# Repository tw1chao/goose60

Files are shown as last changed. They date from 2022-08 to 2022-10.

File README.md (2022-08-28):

# goose60

goose60 是一個 60% 鍵盤 PCB 電路板專案。
設計目標是做出一把**無光害的熱插拔鍵盤**，MCU 採用 ARM Cortex-M3 的 STM32F103。所有按鍵位置皆支援軸體熱插拔，本系列含子專案皆為無光害版本，故電路上僅會有的 `caps lock` 指示燈。

goose60 支援標準60%布局，下面表格列出子專案及支援的布局。

| Sub-Project | Layout |
|---|---|
| JY60 | HHKB |
| Cattle60 | ISO |

未來視情況需要，再新增其他布局的子專案。

## 3D 預覽

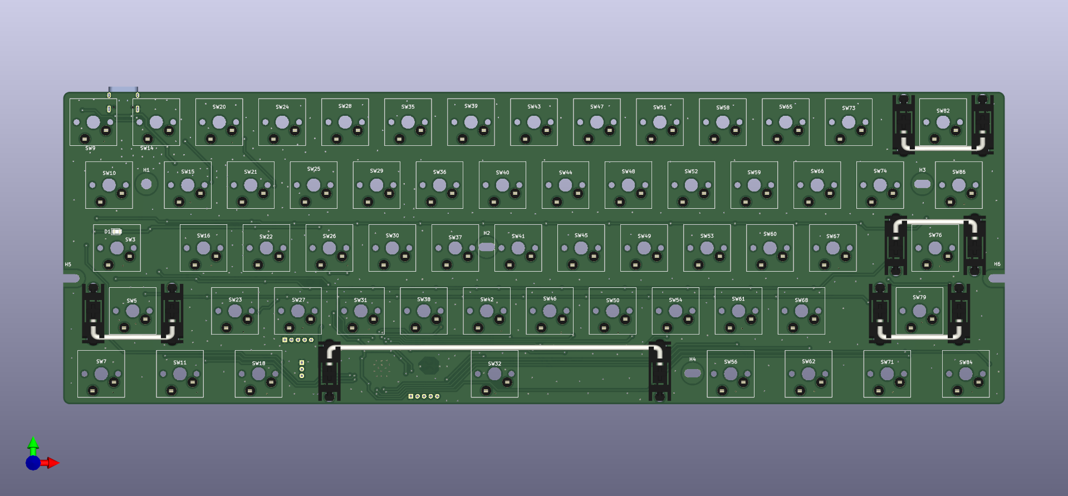
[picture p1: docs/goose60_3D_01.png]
goose60正面

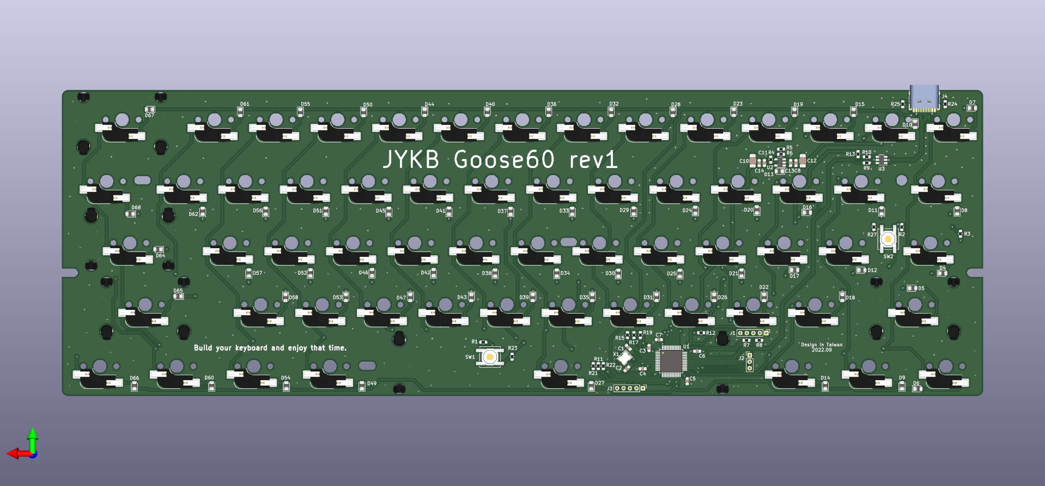
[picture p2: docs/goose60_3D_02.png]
goose60反面


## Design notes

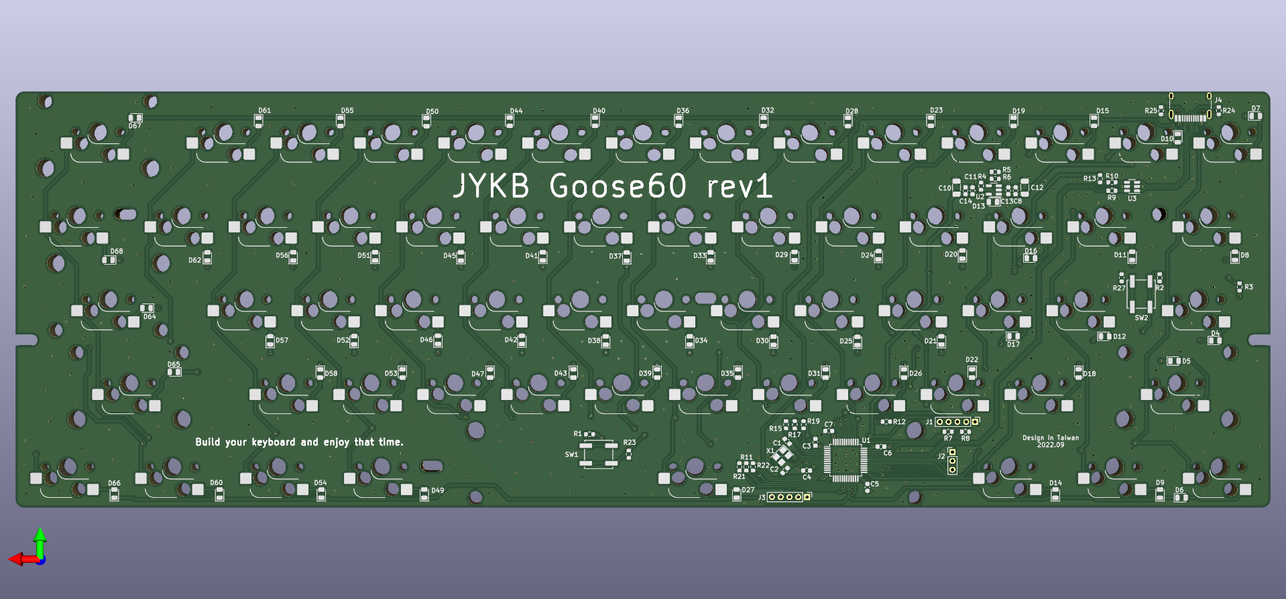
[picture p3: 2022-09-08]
docs/goose60_3D_02_nofp.png

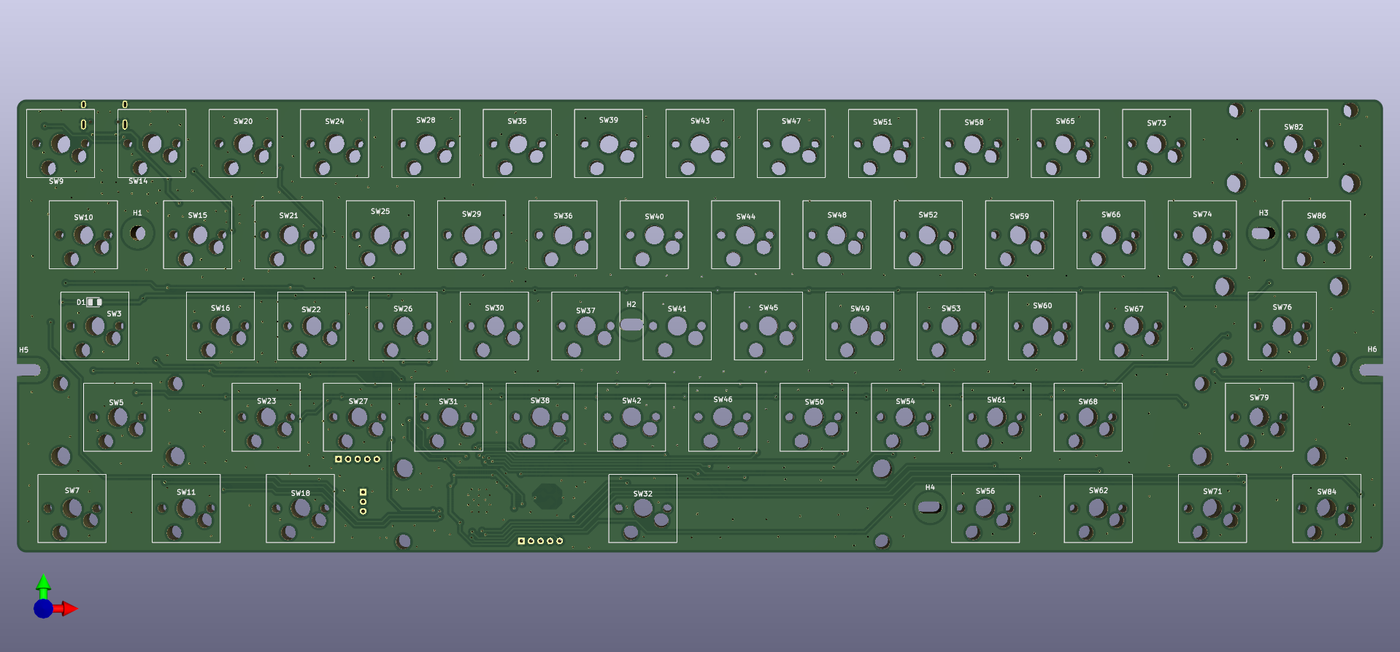
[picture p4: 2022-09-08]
docs/goose60_3D_01_nofp.png

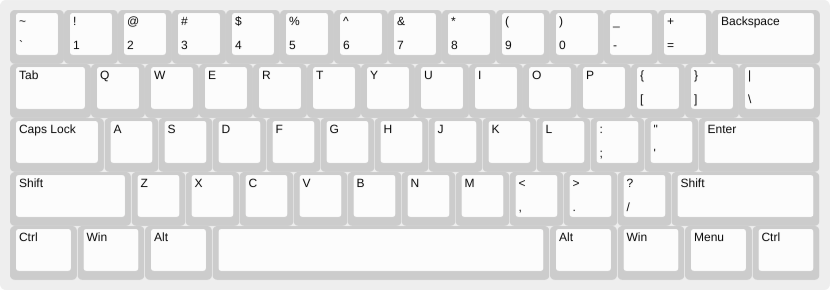
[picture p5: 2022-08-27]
docs/goose60_layout_default.png

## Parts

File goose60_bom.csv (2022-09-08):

ID | 指示符 | 軟體包 | 數量 | 名稱 | 供應商和參考
1 | SW53,SW5,SW71,SW22,SW3,SW10,SW11,SW52,SW20,SW61,SW27,SW35,SW76,SW9,SW65,SW29,SW37,SW41,SW23,SW21,SW82,SW79,SW58,SW67,SW25,SW18,SW59,SW46,SW28,SW43,SW16,SW15,SW7,SW31,SW39,SW73,SW54,SW60,SW32,SW44,SW30,SW47,SW84,SW38,SW45,SW74,SW86,SW40,SW66,SW24,SW50,SW62,SW42,SW48,SW56,SW51,SW49,SW26,SW14,SW36,SW68 | SW_Hotswap_Kailh_MX | 61 | SW_Push
2 | H6,H4,H2,H3,H5,H1 | MountingHole_3.2mm_M3_Pad_TopOnly | 6 | MountingHole
3 | D1 | LED_0805_2012Metric | 1 | LED
4 | C14,C13,C3 | C_0603_1608Metric | 3 | 1uF/16V
5 | D36,D8,D32,D61,D20,D42,D52,D12,D44,D37,D62,D10,D5,D60,D43,D65,D55,D9,D49,D39,D30,D54,D50,D7,D28,D67,D6,D41,D25,D21,D64,D58,D68,D35,D57,D26,D15,D16,D24,D47,D27,D51,D33,D40,D14,D13,D18,D46,D38,D17,D23,D19,D11,D22,D66,D29,D45,D53,D4,D34,D31,D56 | D_0805_2012Metric | 62 | 1N4148
6 | H8,H7 | NetTie-2_SMD_Pad0.5mm | 2 | MountingHole_Pad
7 | R27,R23 | R_0603_1608Metric | 2 | 100K/5%
8 | C7,C5,C6,C11,C8,C4 | C_0603_1608Metric | 6 | 100nF/16V
9 | SW1,SW2 | SW_Push_1P1T_NO_CK_KSC6xxJ | 2 | SW_Push
10 | R3 | R_0603_1608Metric | 1 | 330R/5%
11 | R24,R25 | R_0603_1608Metric | 2 | 5.1K/5%
12 | R10,R9 | R_0603_1608Metric | 2 | 22R/5%
13 | C1,C2 | C_0603_1608Metric | 2 | 22pF/50V
14 | R11,R8,R22,R17,R7,R5,R2,R15,R21,R19,R1 | R_0603_1608Metric | 11 | 10K/5%
15 | R12 | R_0603_1608Metric | 1 | 0R/5%
16 | R4 | R_0603_1608Metric | 1 | 39K/5%
17 | J1 | PinHeader_1x05_P2.00mm_Vertical | 1 | Debugger
18 | R13 | R_0603_1608Metric | 1 | 1.5K/5%
19 | R6 | R_0603_1608Metric | 1 | 100R/5%
20 | U1 | LQFP-48_7x7mm_P0.5mm | 1 | STM32F103CBTx
21 | J3 | PinHeader_1x05_P2.00mm_Vertical | 1 | SPI
22 | C12,C10 | C_1206_3216Metric | 2 | 100uF/16V
23 | J4 | USB_C_Receptacle_HRO_TYPE-C-31-M-12 | 1 | USB_C_Receptacle_USB2.0
24 | X1 | Crystal_SMD_TXC_7M-4Pin_3.2x2.5mm | 1 | Crystal_GND24
25 | U3 | SOT-23-6 | 1 | USBLC6-2SC6
26 | J2 | PinHeader_1x03_P2.00mm_Vertical | 1 | USART
27 | U2 | SOT-23-5 | 1 | TLV75533PDBV

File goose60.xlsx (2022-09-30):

Source: |  | goose60/goose60.kicad_sch
Date:
Tool: |  | Eeschema (6.0.4-0)
Component Count: |  |  | 177
ID | 指示符 | 軟體包 | 數量 | 名稱 | 供應商和參考 | Column1
1 | SW53,SW5,SW71,SW22,SW3,SW10,SW11,SW52,SW20,SW61,SW27,SW35,SW76,SW9,SW65,SW29,SW37,SW41,SW23,SW21,SW82,SW79,SW58,SW67,SW25,SW18,SW59,SW46,SW28,SW43,SW16,SW15,SW7,SW31,SW39,SW73,SW54,SW60,SW32,SW44,SW30,SW47,SW84,SW38,SW45,SW74,SW86,SW40,SW66,SW24,SW50,SW62,SW42,SW48,SW56,SW51,SW49,SW26,SW14,SW36,SW68 | SW_Hotswap_Kailh_MX | 61 | SW_Push
2 | H6,H4,H2,H3,H5,H1 | MountingHole_3.2mm_M3_Pad_TopOnly | 6 | MountingHole
3 | D1 | LED_0805_2012Metric | 1 | LED | https://www.mouser.tw/ProductDetail/Wurth-Elektronik/150080VS75000?qs=LlUlMxKIyB0tGHJmO6%252B0ug%3D%3D
4 | C14,C13,C3 | C_0603_1608Metric | 3 | 1uF/16V | https://www.mouser.tw/ProductDetail/Murata-Electronics/GRM188R61C105MA12D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
5 | D36,D8,D32,D61,D20,D42,D52,D12,D44,D37,D62,D10,D5,D60,D43,D65,D55,D9,D49,D39,D30,D54,D50,D7,D28,D67,D6,D41,D25,D21,D64,D58,D68,D35,D57,D26,D15,D16,D24,D47,D27,D51,D33,D40,D14,D13,D18,D46,D38,D17,D23,D19,D11,D22,D66,D29,D45,D53,D4,D34,D31,D56 | D_0805_2012Metric | 62 | 1N4148 | https://www.mouser.tw/ProductDetail/onsemi-Fairchild/1N4148WS?qs=2%2FYqgE%252BHg%252BKBrKZlAsMLhw%3D%3D
6 | H8,H7 | NetTie-2_SMD_Pad0.5mm | 2 | MountingHole_Pad
7 | R27,R23 | R_0603_1608Metric | 2 | 100K/5% | https://www.mouser.tw/ProductDetail/YAGEO/RC0603JR-07100KL?qs=2cAdsCoAWRG9Rhqklpdeqg%3D%3D
8 | C7,C5,C6,C11,C8,C4 | C_0603_1608Metric | 6 | 100nF/16V | https://www.mouser.tw/ProductDetail/Murata-Electronics/GCM188R71C104KA37J?qs=bGEzvQhTDnZD08oWyjLpYQ%3D%3D
9 | SW1,SW2 | SW_Push_1P1T_NO_CK_KSC6xxJ | 2 | SW_Push
10 | R3 | R_0603_1608Metric | 1 | 330R/5% | https://www.mouser.tw/ProductDetail/YAGEO/AF0603JR-07330RL?qs=tggtontpCXPNcXdAMAy2YQ%3D%3D
11 | R24,R25 | R_0603_1608Metric | 2 | 5.1K/5% | https://www.mouser.tw/ProductDetail/YAGEO/RC0603JR-075K1L?qs=%2F9ZTgpVJnN7YQQgCYZ3hbA%3D%3D
12 | R10,R9 | R_0603_1608Metric | 2 | 22R/5% | https://www.mouser.tw/ProductDetail/YAGEO/RC0603JR-0722RL?qs=%2F9ZTgpVJnN5zDbBVzV1%252B0w%3D%3D
13 | C1,C2 | C_0603_1608Metric | 2 | 22pF/50V | https://www.mouser.tw/ProductDetail/Murata-Electronics/GRM1885C1H220JA01D?qs=1a7qSHAimREG7dNFtPQaOQ%3D%3D
14 | R11,R8,R22,R17,R7,R5,R2,R15,R21,R19,R1 | R_0603_1608Metric | 11 | 10K/5% | https://www.mouser.tw/ProductDetail/YAGEO/RC0603JR-1010KL?qs=IuGqVx9wL0JvLpaswiKGwg%3D%3D
15 | R12 | R_0603_1608Metric | 1 | 0R/5% | https://www.mouser.tw/ProductDetail/YAGEO/RC0603JR-130RL?qs=C8jtsoXSqHT5F5yUCaWiAg%3D%3D
16 | R4 | R_0603_1608Metric | 1 | 39K/5% | https://www.mouser.tw/ProductDetail/YAGEO/RC0603JR-0739KL?qs=%2F9ZTgpVJnN6Z5Io8QsNeJw%3D%3D
17 | J1 | PinHeader_1x05_P2.00mm_Vertical | 1 | Debugger
18 | R13 | R_0603_1608Metric | 1 | 1.5K/5% | https://www.mouser.tw/ProductDetail/YAGEO/RC0603JR-071K5L?qs=%2F9ZTgpVJnN5lp5nC9oG1iw%3D%3D
19 | R6 | R_0603_1608Metric | 1 | 100R/5% | https://www.mouser.tw/ProductDetail/YAGEO/RC0603JR-13100RL?qs=fRxXYNj8ftFxOzR%252BbxPHAw%3D%3D
20 | U1 | LQFP-48_7x7mm_P0.5mm | 1 | STM32F103CBTx | https://www.mouser.tw/ProductDetail/STMicroelectronics/STM32F103CBT6?qs=WxFF5lh7QM3goh6GV5Ogig%3D%3D
21 | J3 | PinHeader_1x05_P2.00mm_Vertical | 1 | SPI
22 | C12,C10 | C_1206_3216Metric | 2 | 100uF/16V | https://www.mouser.tw/ProductDetail/Murata-Electronics/GRM31CR60G107MEA8L?qs=hd1VzrDQEGj2cLQFhjz5Pg%3D%3D
23 | J4 | USB_C_Receptacle_HRO_TYPE-C-31-M-12 | 1 | USB_C_Receptacle_USB2.0
24 | X1 | Crystal_SMD_TXC_7M-4Pin_3.2x2.5mm | 1 | Crystal_GND24 | https://www.mouser.tw/ProductDetail/Wurth-Elektronik/830108313809?qs=hd1VzrDQEGg8Y0DXLkvT4A%3D%3D
25 | U3 | SOT-23-6 | 1 | USBLC6-2SC6 | https://www.mouser.tw/ProductDetail/STMicroelectronics/USBLC6-2SC6?qs=po45yt2pPpu%2FhNIlwQdTlg%3D%3D
26 | J2 | PinHeader_1x03_P2.00mm_Vertical | 1 | USART
27 | U2 | SOT-23-5 | 1 | TLV75533PDBV | https://www.mouser.tw/ProductDetail/Texas-Instruments/TLV75533PDBVR?qs=55YtniHzbhAKEwqeO2xJXQ%3D%3D

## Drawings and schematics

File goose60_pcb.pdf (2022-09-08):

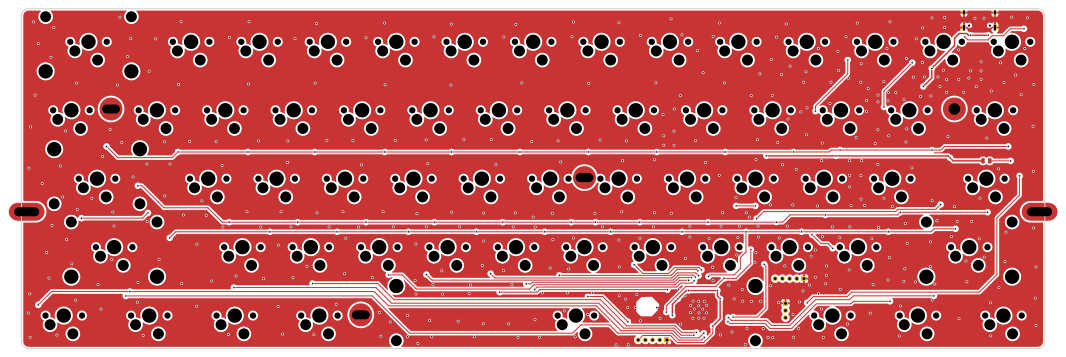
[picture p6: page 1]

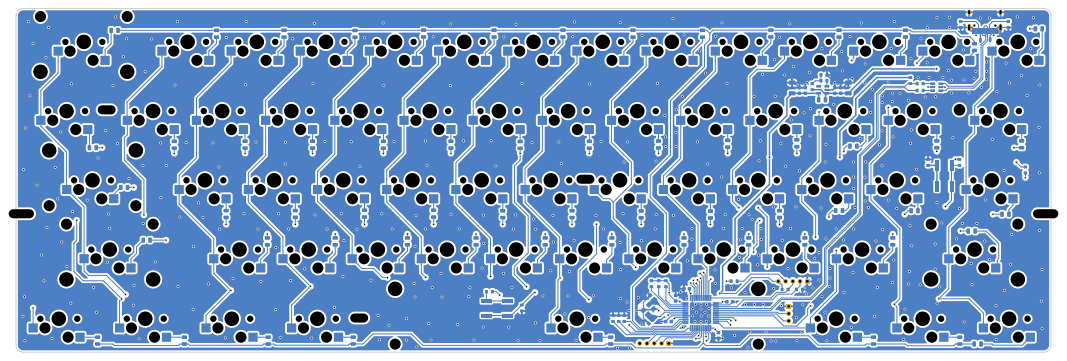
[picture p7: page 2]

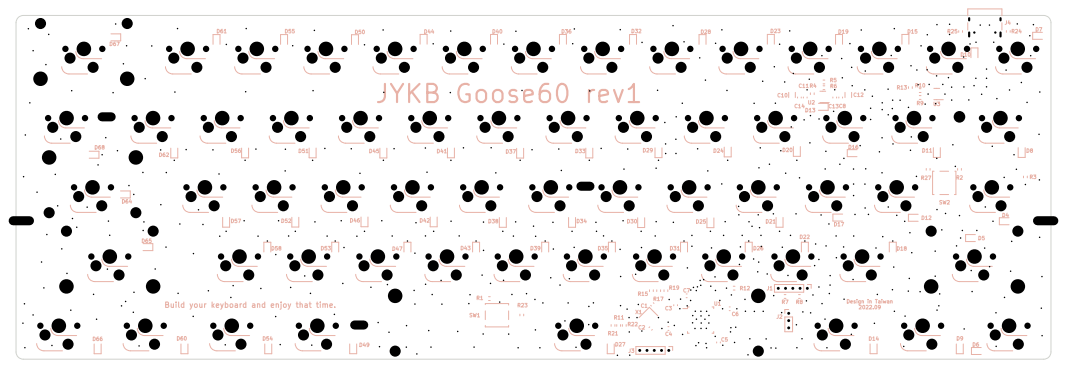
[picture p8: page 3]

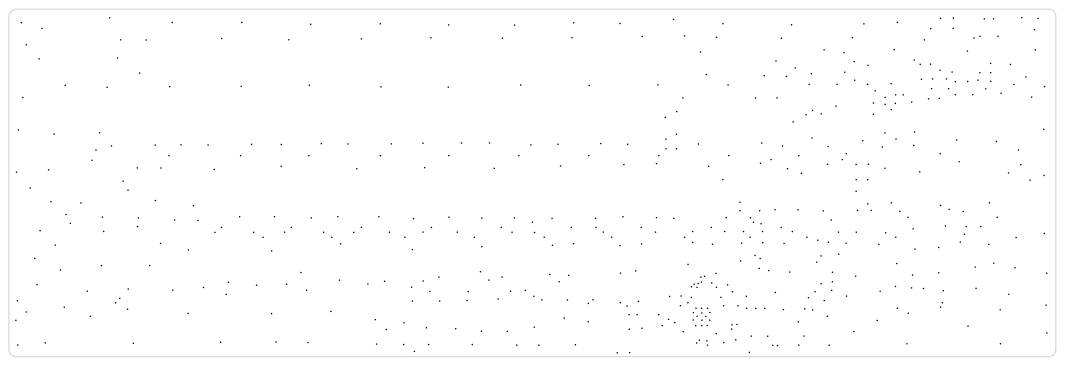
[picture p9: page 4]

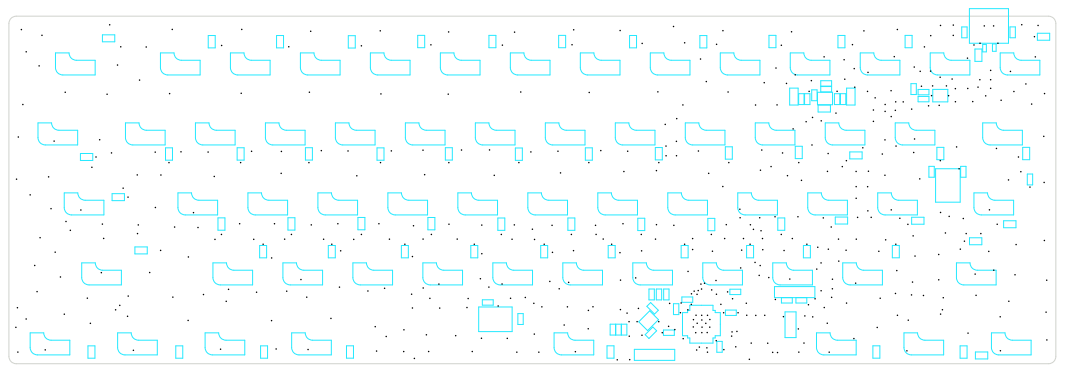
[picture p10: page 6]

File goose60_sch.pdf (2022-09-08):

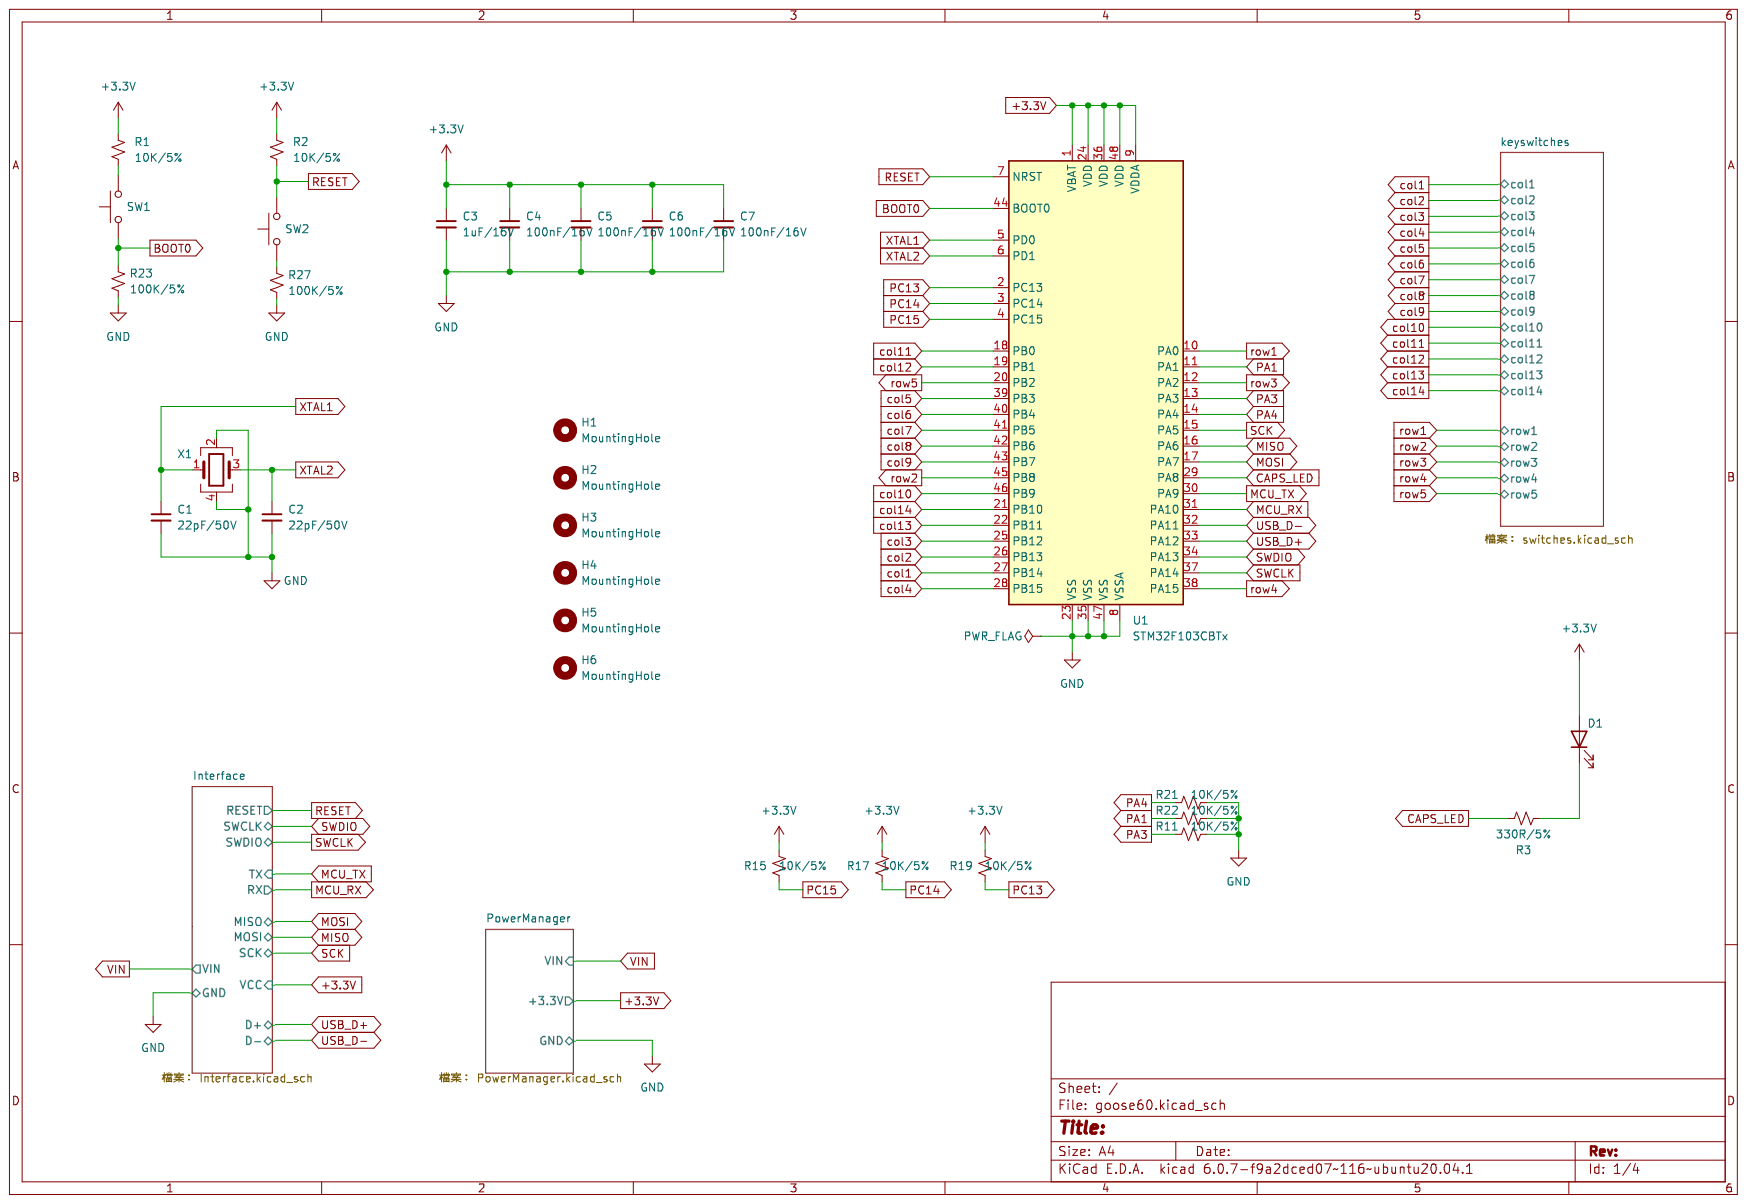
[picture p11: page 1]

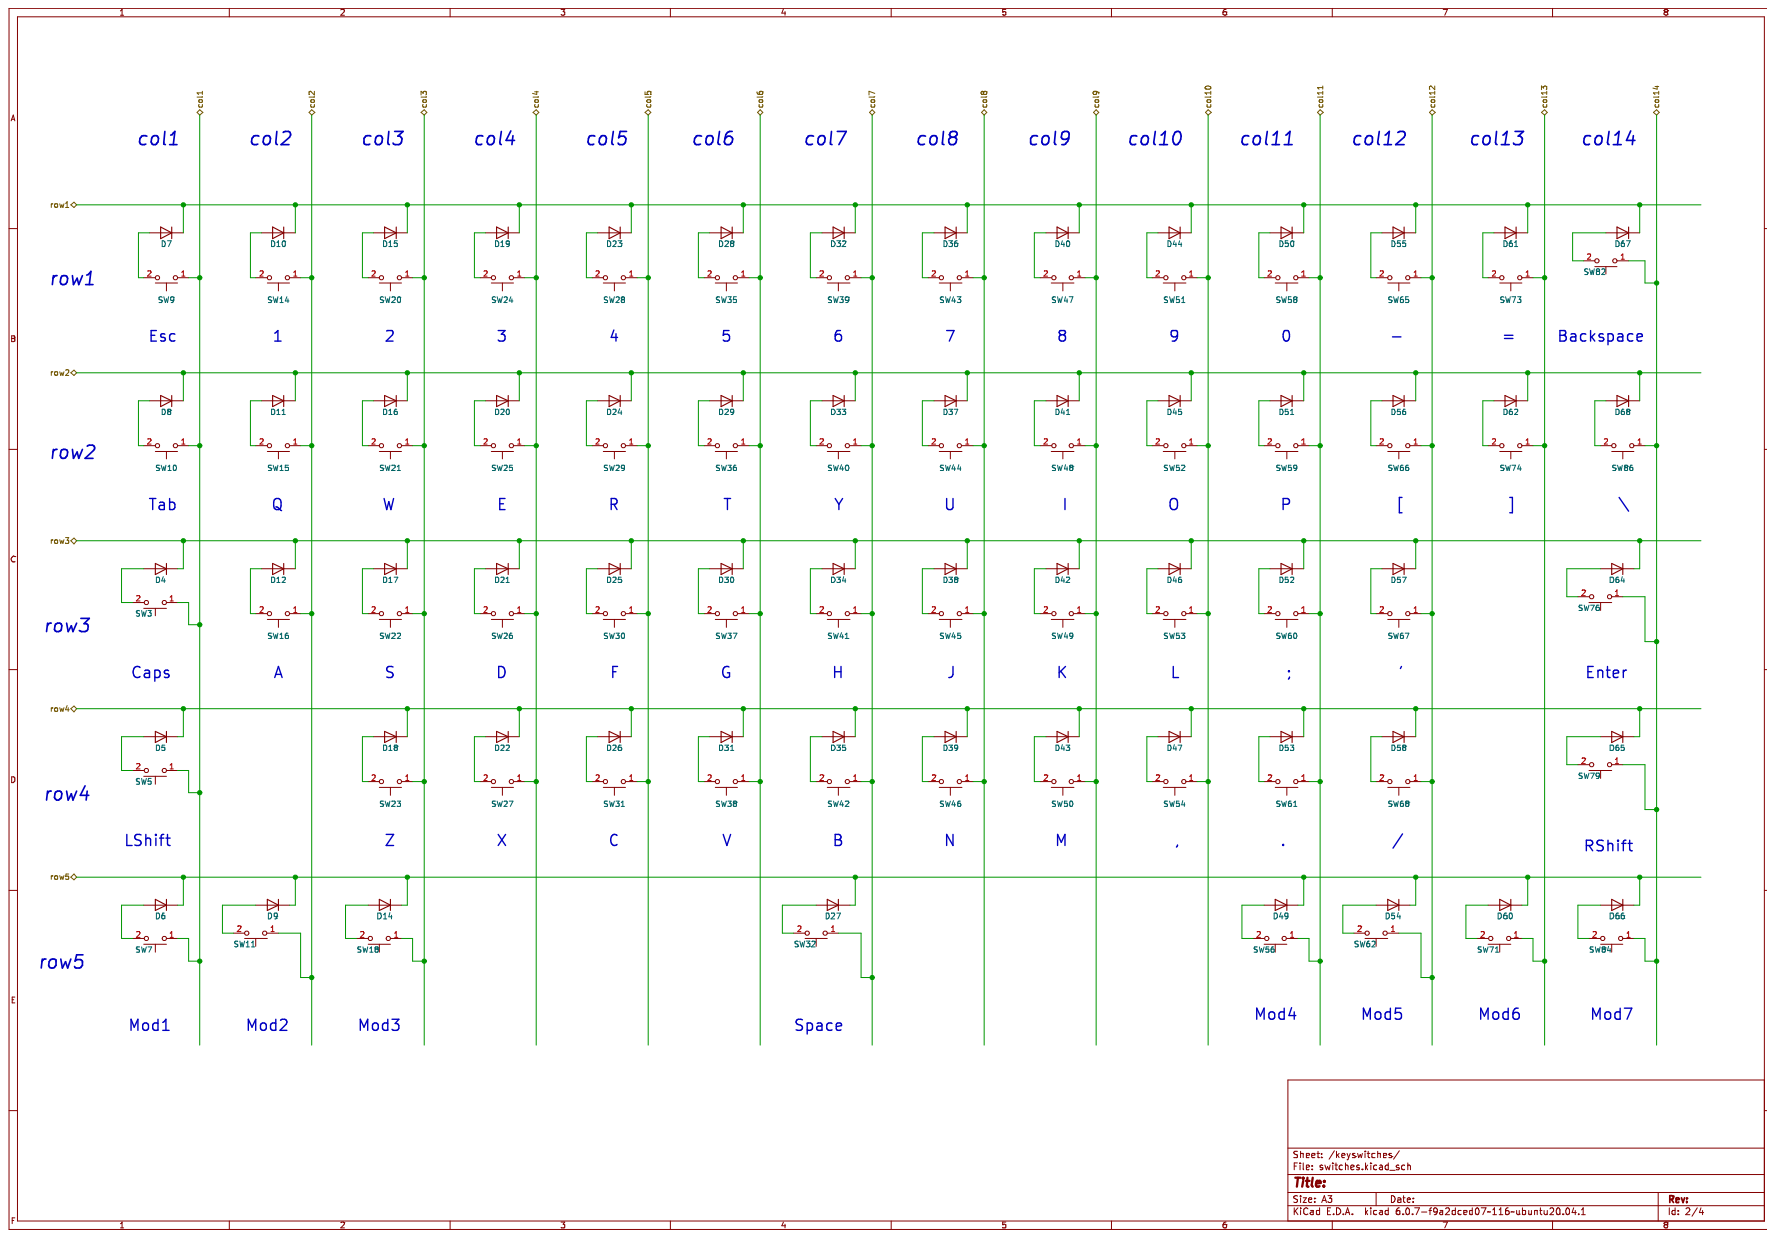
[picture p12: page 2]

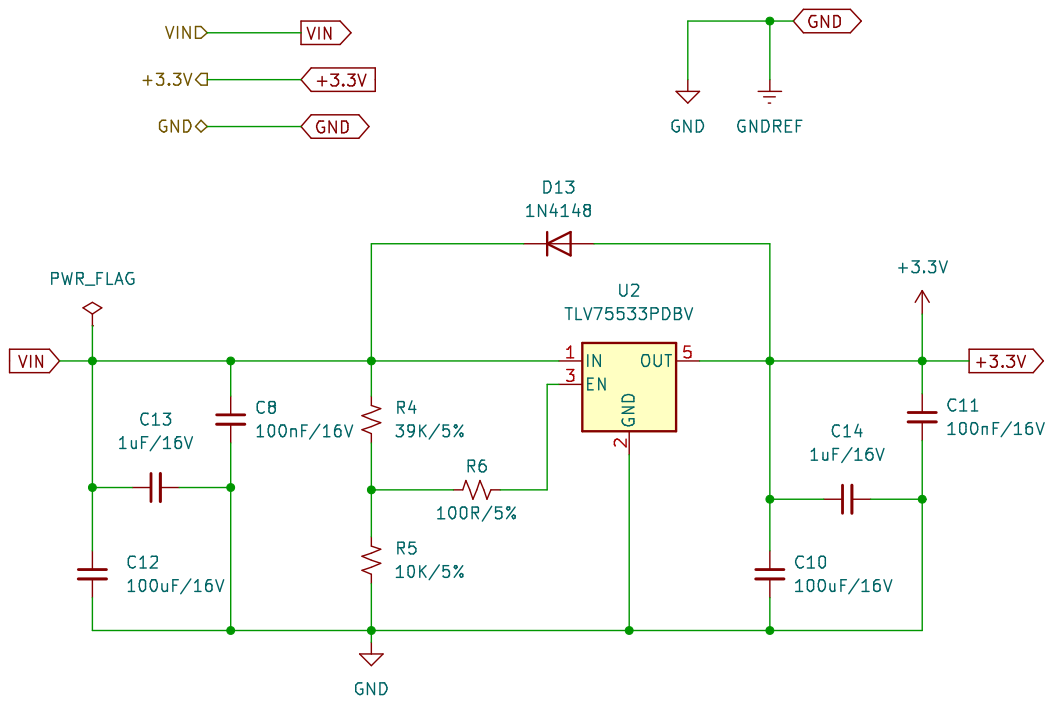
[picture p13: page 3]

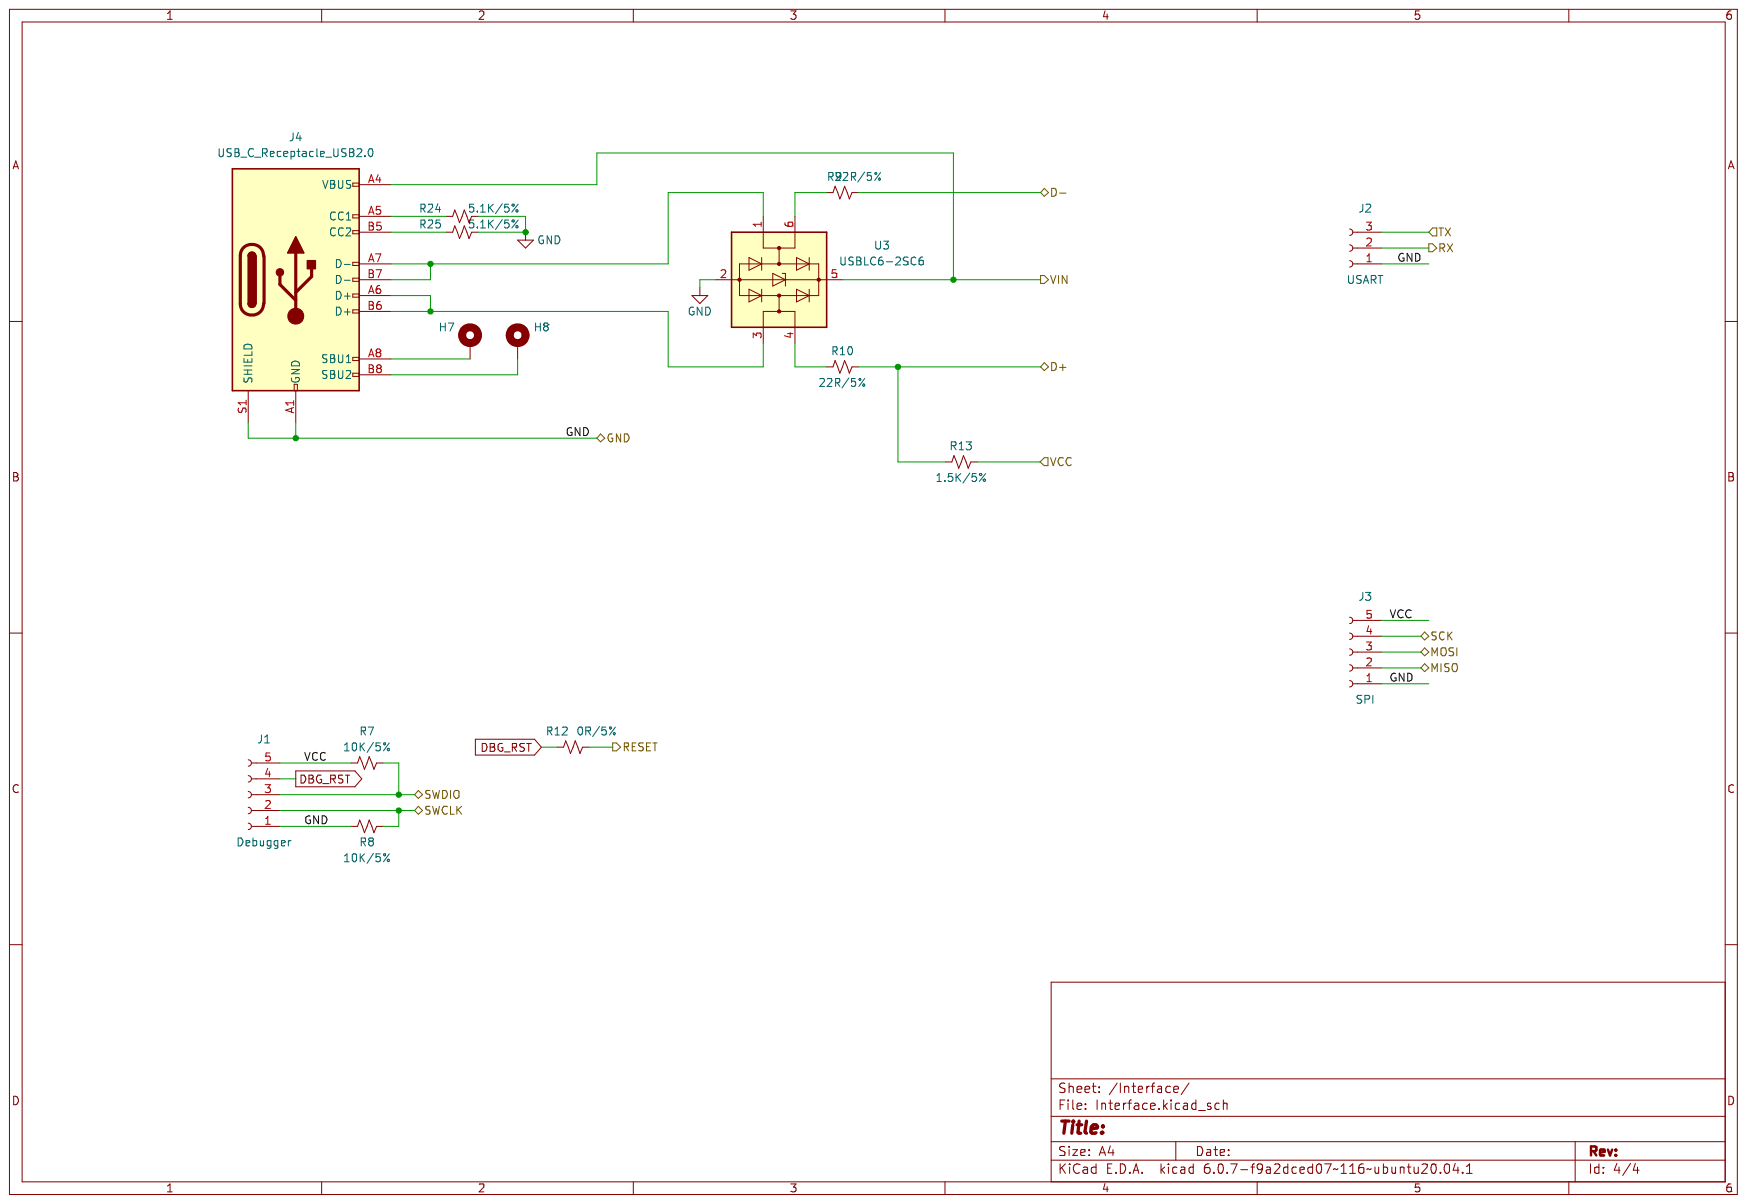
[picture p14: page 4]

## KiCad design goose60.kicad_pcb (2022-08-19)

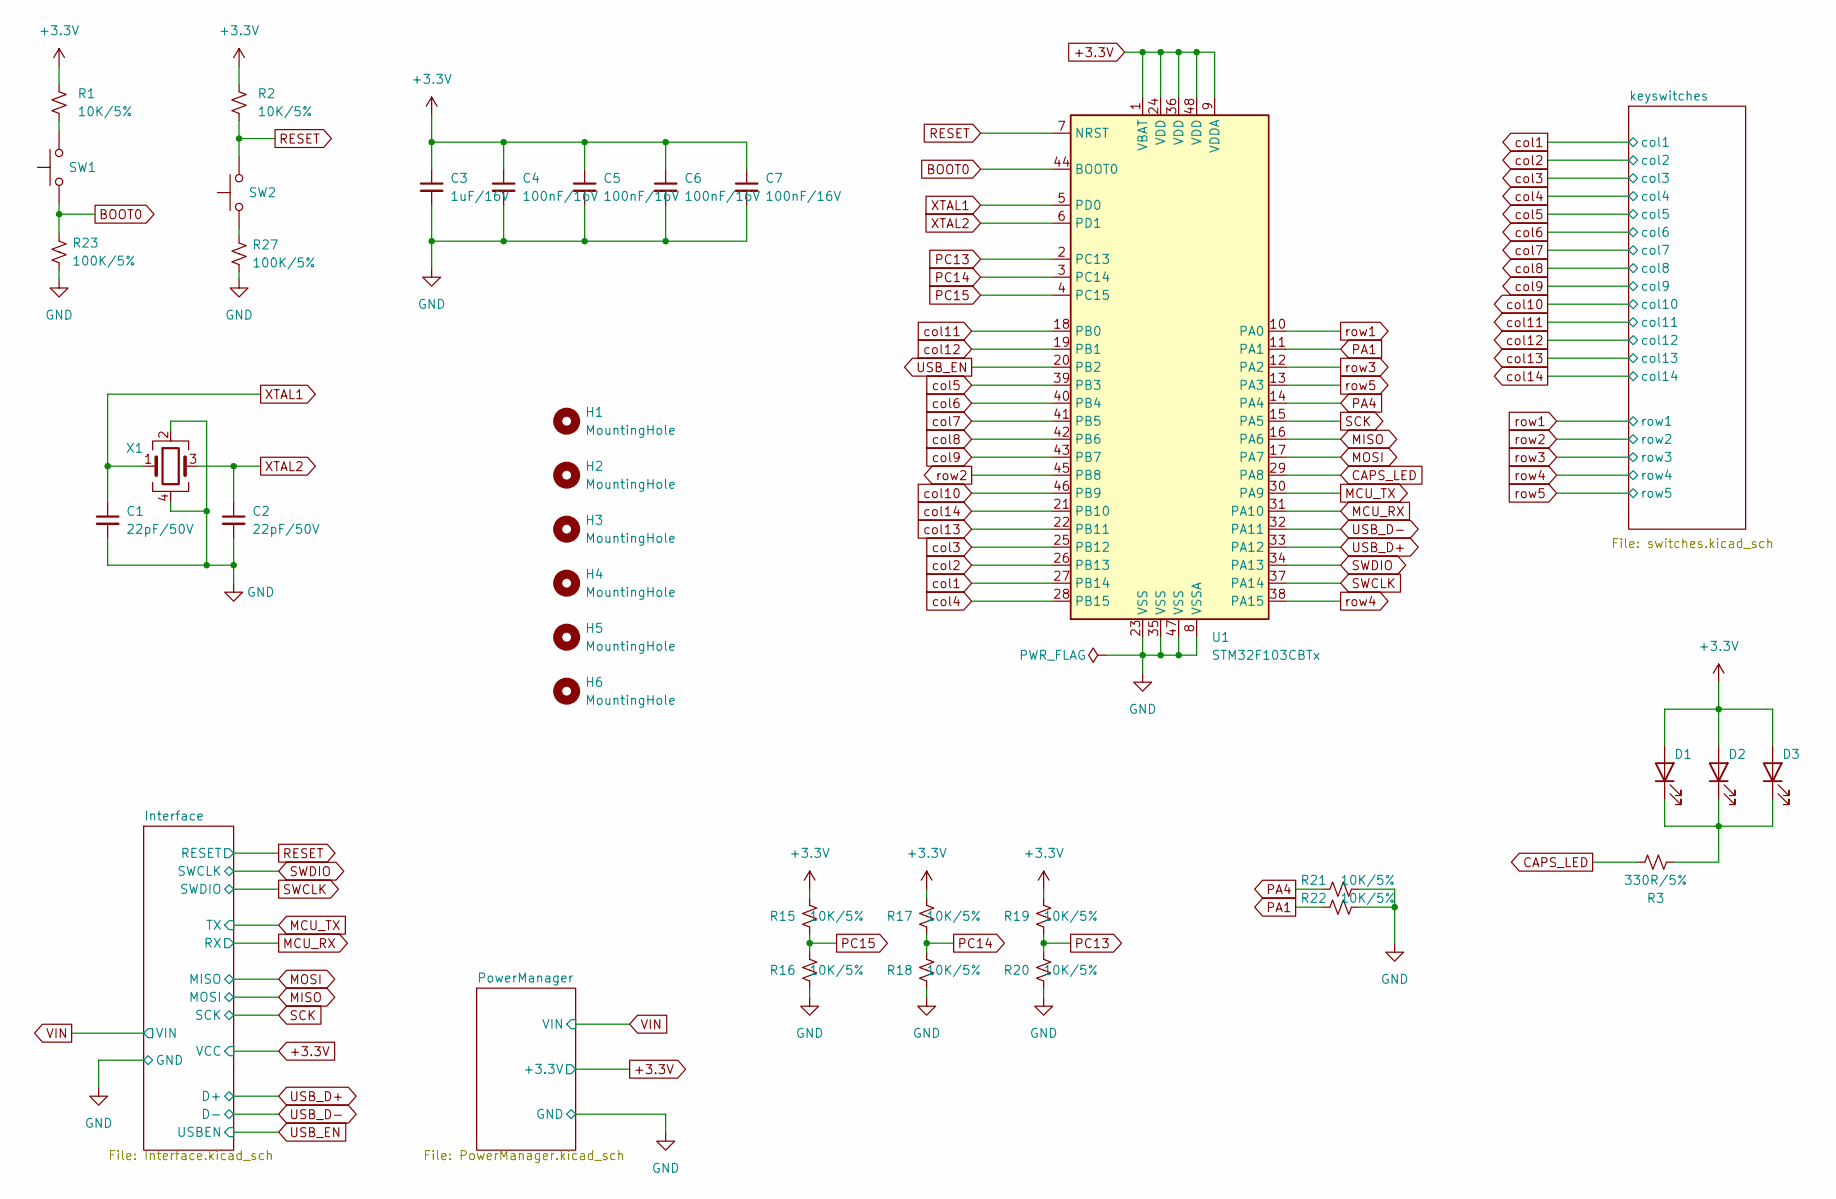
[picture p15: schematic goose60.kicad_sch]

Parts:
C1, C2: 22pF/50V; C_0603_1608Metric
C3: 1uF/16V; C_0603_1608Metric
C4, C5, C6, C7: 100nF/16V; C_0603_1608Metric
D1, D2, D3: LED; LED_0805_2012Metric
H1: MountingHole; MountingHole_3.2mm_M3_Pad
H2, H3, H4, H5, H6: MountingHole; MountingHole_3.2mm_M3_Pad_TopOnly
R1, R2, R15, R16, R17, R18, R19, R20, R21, R22: 10K/5%; R_0603_1608Metric
R3: 330R/5%; R_0603_1608Metric
R23, R27: 100K/5%; R_0603_1608Metric
SW1, SW2: SW_Push; SW_Push_1P1T_NO_CK_KSC6xxJ
U1: STM32F103CBTx; LQFP-48_7x7mm_P0.5mm
X1: Crystal_GND24; Crystal_SMD_TXC_7M-4Pin_3.2x2.5mm

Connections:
+3.3V: C3.1, C4.1, C5.1, C6.1, C7.1, D1.2 (A), D2.2 (A), D3.2 (A), R1.1, R2.1, R15.1, R17.1, R19.1, U1.1 (VBAT), U1.9 (VDDA), U1.24 (VDD), U1.36 (VDD), U1.48 (VDD); also elsewhere on the board
BOOT0: R23.1, SW1.1, U1.44 (BOOT0)
CAPS_LED: R3.2, U1.29 (PA8)
GND: C1.2, C2.2, C3.2, C4.2, C5.2, C6.2, C7.2, R16.2, R18.2, R20.2, R21.1, R22.1, R23.2, R27.2, U1.8 (VSSA), U1.23 (VSS), U1.35 (VSS), U1.47 (VSS), X1.2, X1.4; also elsewhere on the board
MCU_RX: U1.31 (PA10); also elsewhere on the board
MCU_TX: U1.30 (PA9); also elsewhere on the board
MISO: U1.16 (PA6); also elsewhere on the board
MOSI: U1.17 (PA7); also elsewhere on the board
unnamed: D1.1 (K), D2.1 (K), D3.1 (K), R3.1
unnamed: R1.2, SW1.2
unnamed: R27.1, SW2.1
PA1: R22.2, U1.11 (PA1)
PA4: R21.2, U1.14 (PA4)
PC13: R19.2, R20.1, U1.2 (PC13)
PC14: R17.2, R18.1, U1.3 (PC14)
PC15: R15.2, R16.1, U1.4 (PC15)
RESET: R2.2, SW2.2, U1.7 (NRST); also elsewhere on the board
SCK: U1.15 (PA5); also elsewhere on the board
SWCLK: U1.37 (PA14); also elsewhere on the board
SWDIO: U1.34 (PA13); also elsewhere on the board
USB_D+: U1.33 (PA12); also elsewhere on the board
USB_D-: U1.32 (PA11); also elsewhere on the board
USB_EN: U1.20 (PB2); also elsewhere on the board
XTAL1: C1.1, U1.5 (PD0), X1.1
XTAL2: C2.1, U1.6 (PD1), X1.3
col1: U1.27 (PB14); also elsewhere on the board
col2: U1.26 (PB13); also elsewhere on the board
col3: U1.25 (PB12); also elsewhere on the board
col4: U1.28 (PB15); also elsewhere on the board
col5: U1.39 (PB3); also elsewhere on the board
col6: U1.40 (PB4); also elsewhere on the board
col7: U1.41 (PB5); also elsewhere on the board
col8: U1.42 (PB6); also elsewhere on the board
col9: U1.43 (PB7); also elsewhere on the board
col10: U1.46 (PB9); also elsewhere on the board
col11: U1.18 (PB0); also elsewhere on the board
col12: U1.19 (PB1); also elsewhere on the board
col13: U1.22 (PB11); also elsewhere on the board
col14: U1.21 (PB10); also elsewhere on the board
row1: U1.10 (PA0); also elsewhere on the board
row2: U1.45 (PB8); also elsewhere on the board
row3: U1.12 (PA2); also elsewhere on the board
row4: U1.38 (PA15); also elsewhere on the board
row5: U1.13 (PA3); also elsewhere on the board

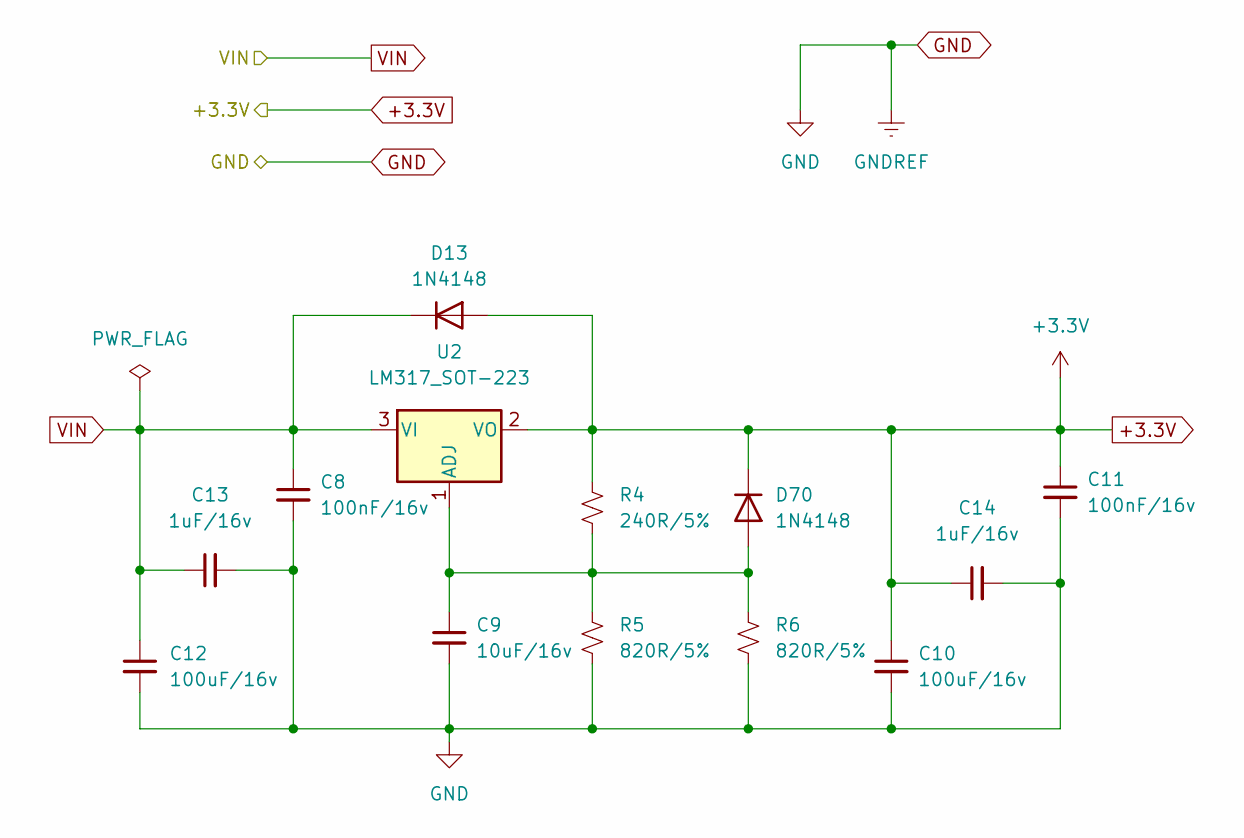
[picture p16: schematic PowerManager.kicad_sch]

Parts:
C8, C11: 100nF/16v; C_0603_1608Metric
C9: 10uF/16v; C_0805_2012Metric
C10, C12: 100uF/16v; C_1206_3216Metric
C13, C14: 1uF/16v; C_0603_1608Metric
D13, D70: 1N4148; D_0805_2012Metric
R4: 240R/5%; R_0603_1608Metric
R5, R6: 820R/5%; R_0603_1608Metric
U2: LM317_SOT-223; SOT-223-3_TabPin2

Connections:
+3.3V: C10.1, C11.1, C14.1, D13.2 (A), D70.1 (K), R4.1, U2.2 (VO); also elsewhere on the board
GND: C8.2, C9.2, C10.2, C11.2, C12.2, C13.2, C14.2, R5.2, R6.2; also elsewhere on the board
unnamed: C9.1, D70.2 (A), R4.2, R5.1, R6.1, U2.1 (ADJ)
VIN: C8.1, C12.1, C13.1, D13.1 (K), U2.3 (VI); also elsewhere on the board

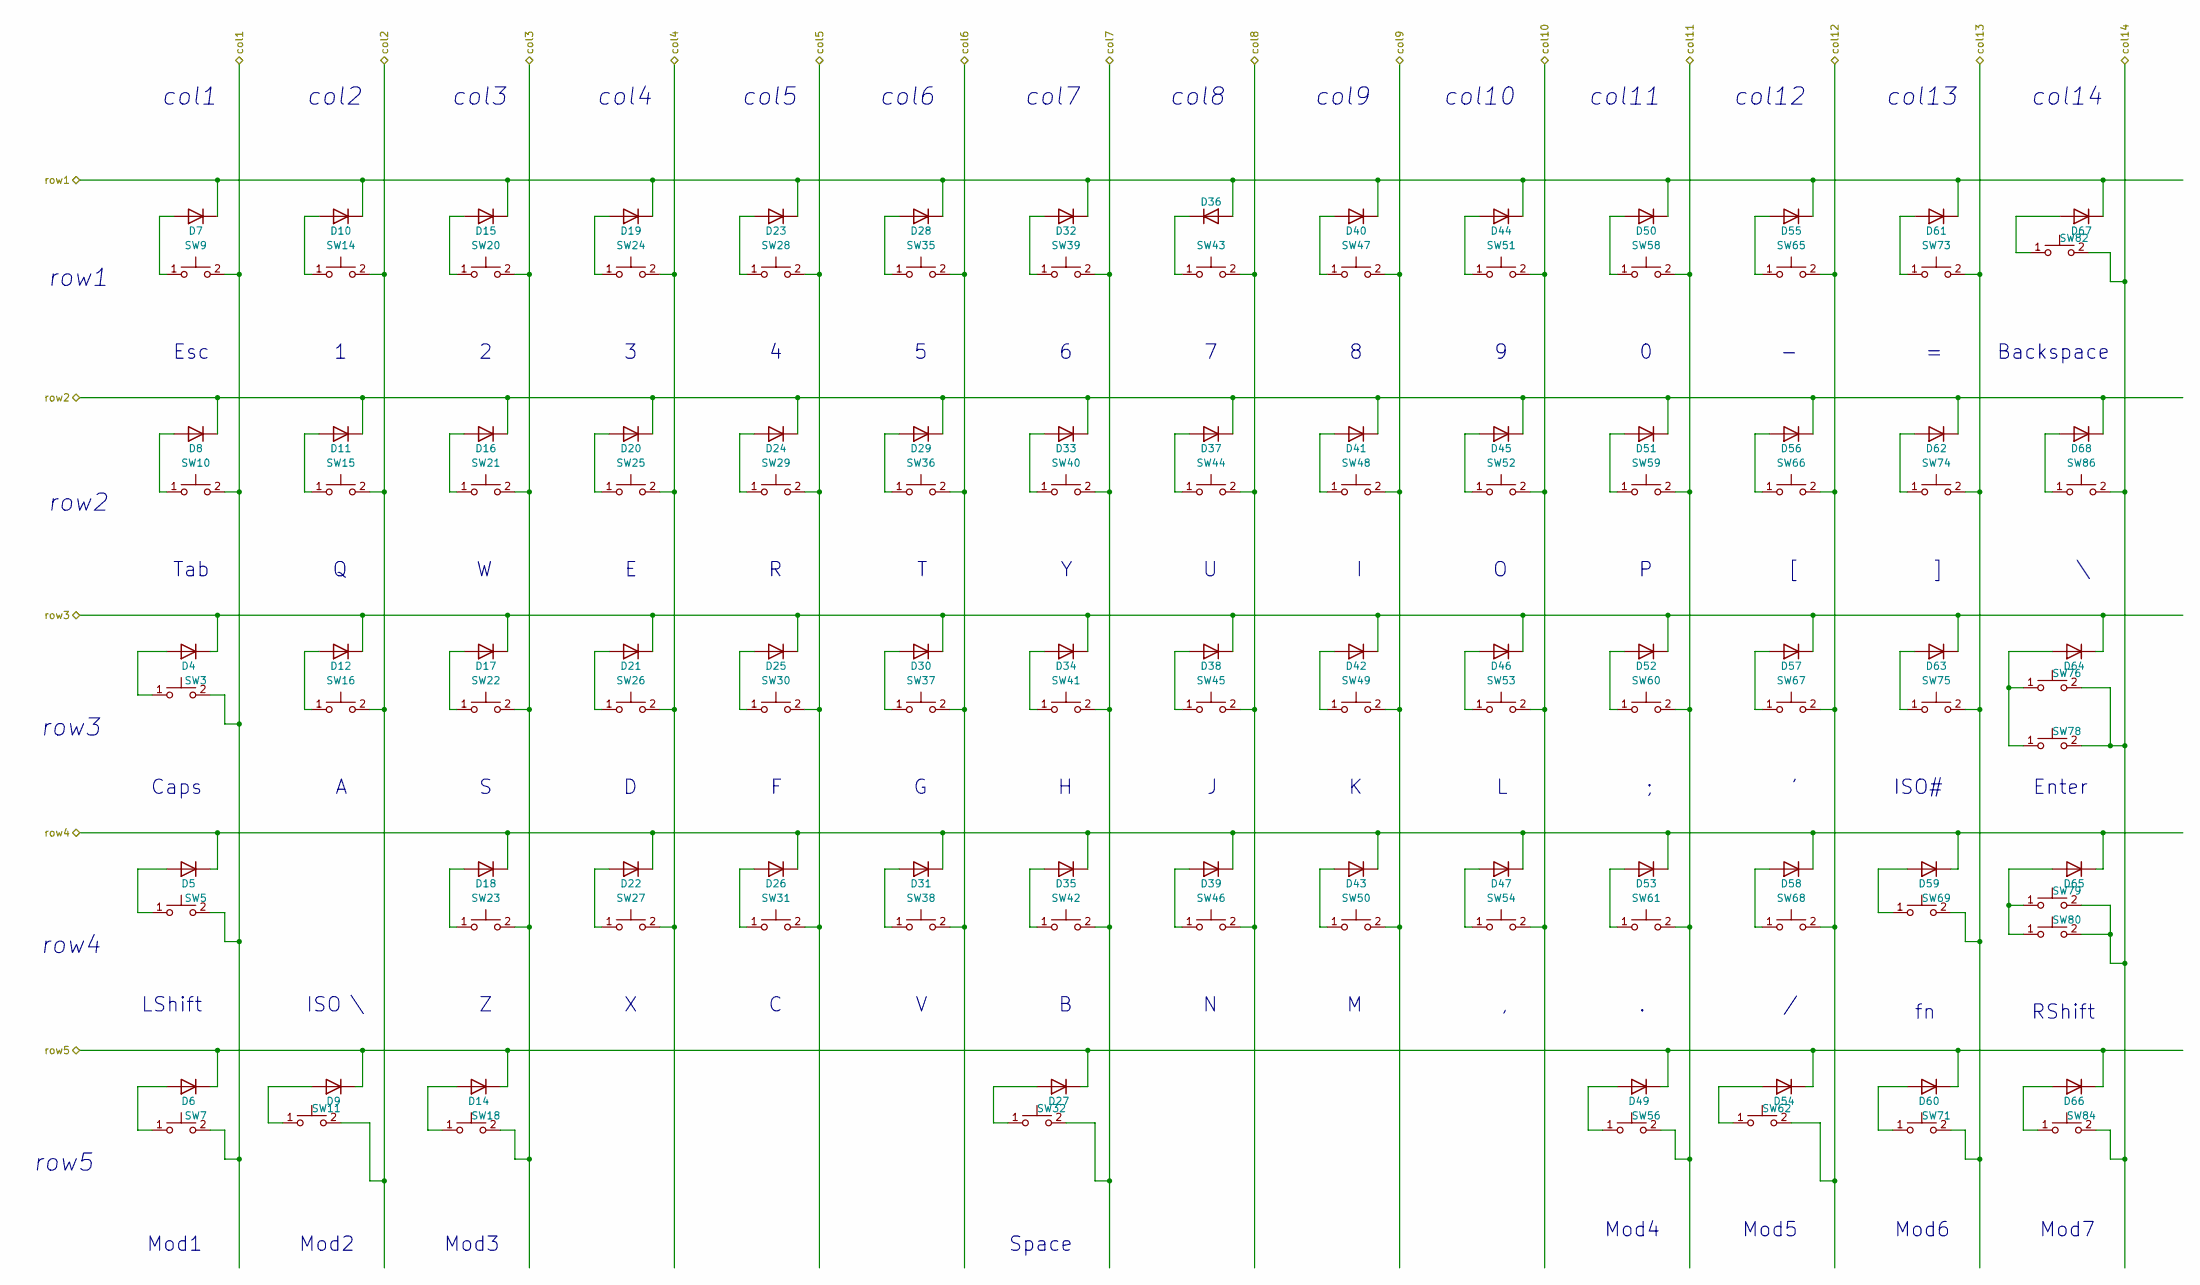
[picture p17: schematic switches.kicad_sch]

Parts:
D4, D5, D6, D7, D8, D9, D10, D11, D12, D14, D15, D16, D17, D18, D19, D20, D21, D22, D23, D24, D25, D26, D27, D28, D29, D30, D31, D32, D33, D34, D35, D36, D37, D38, D39, D40, D41, D42, D43, D44, D45, D46, D47, D49, D50, D51, D52, D53, D54, D55, D56, D57, D58, D59, D60, D61, D62, D63, D64, D65, D66, D67, D68: 1N4148; D_0805_2012Metric
SW3, SW5, SW7, SW9, SW10, SW11, SW14, SW15, SW16, SW18, SW20, SW21, SW22, SW23, SW24, SW25, SW26, SW27, SW28, SW29, SW30, SW31, SW32, SW35, SW36, SW37, SW38, SW39, SW40, SW41, SW42, SW43, SW44, SW45, SW46, SW47, SW48, SW49, SW50, SW51, SW52, SW53, SW54, SW56, SW58, SW59, SW60, SW61, SW62, SW65, SW66, SW67, SW68, SW69, SW71, SW73, SW74, SW75, SW76, SW78, SW79, SW80, SW82, SW84, SW86: SW_Push; Kailh_socket_MX

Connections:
unnamed: D4.2 (A), SW3.1
unnamed: D5.2 (A), SW5.1
unnamed: D6.2 (A), SW7.1
unnamed: D7.2 (A), SW9.1
unnamed: D8.2 (A), SW10.1
unnamed: D9.2 (A), SW11.1
unnamed: D10.2 (A), SW14.1
unnamed: D11.2 (A), SW15.1
unnamed: D12.2 (A), SW16.1
unnamed: D14.2 (A), SW18.1
unnamed: D15.2 (A), SW20.1
unnamed: D16.2 (A), SW21.1
unnamed: D17.2 (A), SW22.1
unnamed: D18.2 (A), SW23.1
unnamed: D19.2 (A), SW24.1
unnamed: D20.2 (A), SW25.1
unnamed: D21.2 (A), SW26.1
unnamed: D22.2 (A), SW27.1
unnamed: D23.2 (A), SW28.1
unnamed: D24.2 (A), SW29.1
unnamed: D25.2 (A), SW30.1
unnamed: D26.2 (A), SW31.1
unnamed: D27.2 (A), SW32.1
unnamed: D28.2 (A), SW35.1
unnamed: D29.2 (A), SW36.1
unnamed: D30.2 (A), SW37.1
unnamed: D31.2 (A), SW38.1
unnamed: D32.2 (A), SW39.1
unnamed: D33.2 (A), SW40.1
unnamed: D34.2 (A), SW41.1
unnamed: D35.2 (A), SW42.1
unnamed: D36.1 (K), SW43.1
unnamed: D37.2 (A), SW44.1
unnamed: D38.2 (A), SW45.1
unnamed: D39.2 (A), SW46.1
unnamed: D40.2 (A), SW47.1
unnamed: D41.2 (A), SW48.1
unnamed: D42.2 (A), SW49.1
unnamed: D43.2 (A), SW50.1
unnamed: D44.2 (A), SW51.1
unnamed: D45.2 (A), SW52.1
unnamed: D46.2 (A), SW53.1
unnamed: D47.2 (A), SW54.1
unnamed: D49.2 (A), SW56.1
unnamed: D50.2 (A), SW58.1
unnamed: D51.2 (A), SW59.1
unnamed: D52.2 (A), SW60.1
unnamed: D53.2 (A), SW61.1
unnamed: D54.2 (A), SW62.1
unnamed: D55.2 (A), SW65.1
unnamed: D56.2 (A), SW66.1
unnamed: D57.2 (A), SW67.1
unnamed: D58.2 (A), SW68.1
unnamed: D59.2 (A), SW69.1
unnamed: D60.2 (A), SW71.1
unnamed: D61.2 (A), SW73.1
unnamed: D62.2 (A), SW74.1
unnamed: D63.2 (A), SW75.1
unnamed: D64.2 (A), SW76.1, SW78.1
unnamed: D65.2 (A), SW79.1, SW80.1
unnamed: D66.2 (A), SW84.1
unnamed: D67.2 (A), SW82.1
unnamed: D68.2 (A), SW86.1
col1: SW3.2, SW5.2, SW7.2, SW9.2, SW10.2; also elsewhere on the board
col2: SW11.2, SW14.2, SW15.2, SW16.2; also elsewhere on the board
col3: SW18.2, SW20.2, SW21.2, SW22.2, SW23.2; also elsewhere on the board
col4: SW24.2, SW25.2, SW26.2, SW27.2; also elsewhere on the board
col5: SW28.2, SW29.2, SW30.2, SW31.2; also elsewhere on the board
col6: SW35.2, SW36.2, SW37.2, SW38.2; also elsewhere on the board
col7: SW32.2, SW39.2, SW40.2, SW41.2, SW42.2; also elsewhere on the board
col8: SW43.2, SW44.2, SW45.2, SW46.2; also elsewhere on the board
col9: SW47.2, SW48.2, SW49.2, SW50.2; also elsewhere on the board
col10: SW51.2, SW52.2, SW53.2, SW54.2; also elsewhere on the board
col11: SW56.2, SW58.2, SW59.2, SW60.2, SW61.2; also elsewhere on the board
col12: SW62.2, SW65.2, SW66.2, SW67.2, SW68.2; also elsewhere on the board
col13: SW69.2, SW71.2, SW73.2, SW74.2, SW75.2; also elsewhere on the board
col14: SW76.2, SW78.2, SW79.2, SW80.2, SW82.2, SW84.2, SW86.2; also elsewhere on the board
row1: D7.1 (K), D10.1 (K), D15.1 (K), D19.1 (K), D23.1 (K), D28.1 (K), D32.1 (K), D36.2 (A), D40.1 (K), D44.1 (K), D50.1 (K), D55.1 (K), D61.1 (K), D67.1 (K); also elsewhere on the board
row2: D8.1 (K), D11.1 (K), D16.1 (K), D20.1 (K), D24.1 (K), D29.1 (K), D33.1 (K), D37.1 (K), D41.1 (K), D45.1 (K), D51.1 (K), D56.1 (K), D62.1 (K), D68.1 (K); also elsewhere on the board
row3: D4.1 (K), D12.1 (K), D17.1 (K), D21.1 (K), D25.1 (K), D30.1 (K), D34.1 (K), D38.1 (K), D42.1 (K), D46.1 (K), D52.1 (K), D57.1 (K), D63.1 (K), D64.1 (K); also elsewhere on the board
row4: D5.1 (K), D18.1 (K), D22.1 (K), D26.1 (K), D31.1 (K), D35.1 (K), D39.1 (K), D43.1 (K), D47.1 (K), D53.1 (K), D58.1 (K), D59.1 (K), D65.1 (K); also elsewhere on the board
row5: D6.1 (K), D9.1 (K), D14.1 (K), D27.1 (K), D49.1 (K), D54.1 (K), D60.1 (K), D66.1 (K); also elsewhere on the board

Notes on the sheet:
col1
ISO#
col3
ISO \
Mod2
row1
col9
col6
Mod3
Mod7
col13
col4
Backspace
col14
col11
col12
Mod5
RShift
row3
LShift
row5
col10
Mod1
Space
Esc
col5
col7
Caps
col8
Mod6
col2
Enter
row2
row4
Mod4
Tab

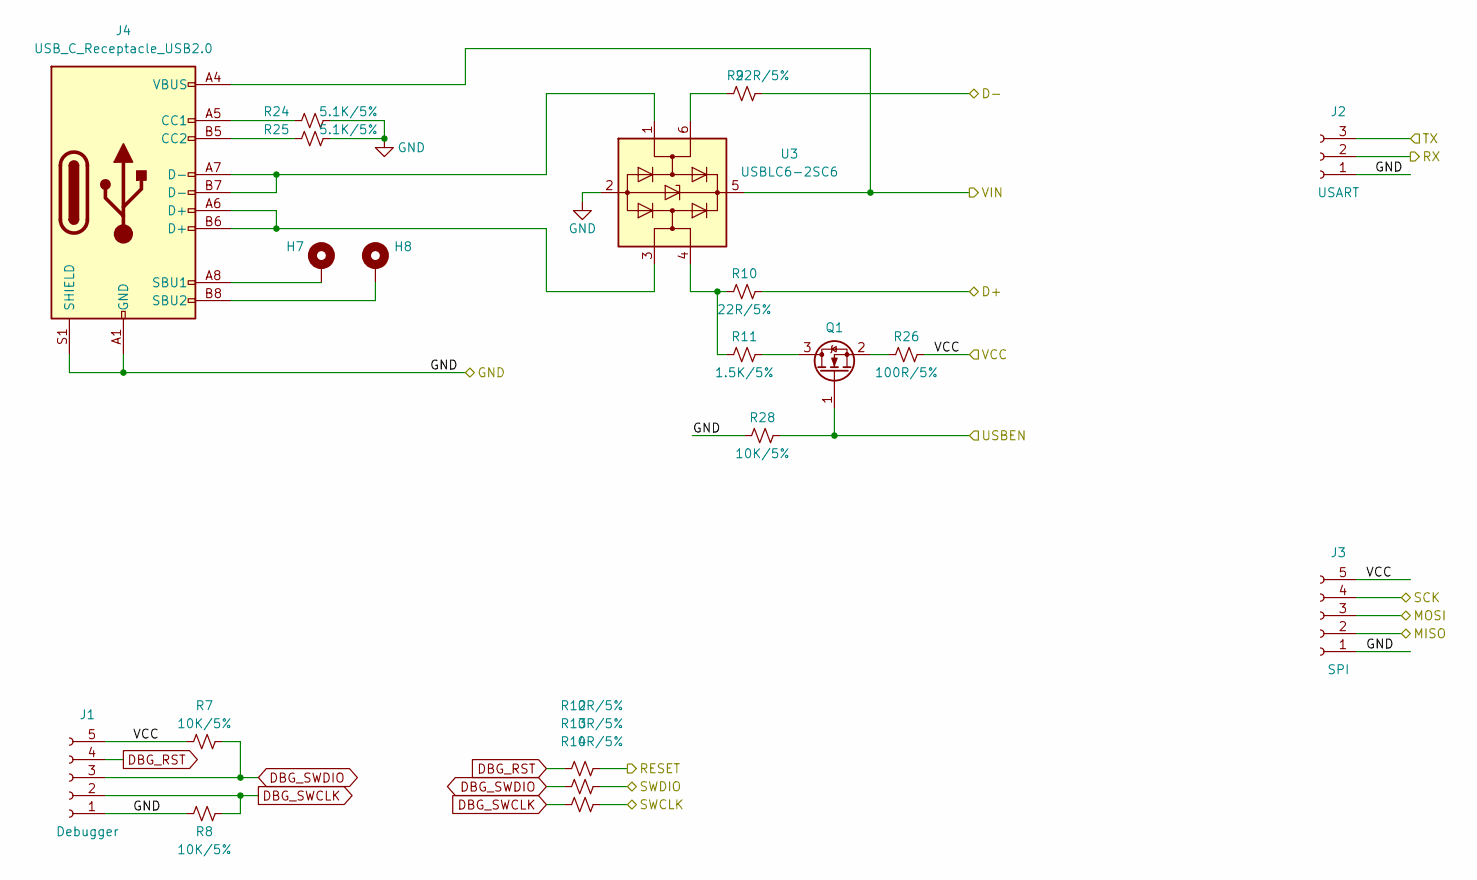
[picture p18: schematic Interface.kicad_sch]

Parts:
H7, H8: MountingHole_Pad; NetTie-2_SMD_Pad0.5mm
J1: Debugger; PinHeader_1x05_P2.00mm_Vertical
J2: USART; PinHeader_1x03_P2.00mm_Vertical
J3: SPI; PinHeader_1x05_P2.00mm_Vertical
J4: USB_C_Receptacle_USB2.0; USB_C_Receptacle_HRO_TYPE-C-31-M-12
Q1: Q_NMOS_GSD; SOT-23
R7, R8, R28: 10K/5%; R_0603_1608Metric
R9, R10: 22R/5%; R_0603_1608Metric
R11: 1.5K/5%; R_0603_1608Metric
R12, R13, R14: 0R/5%; R_0603_1608Metric
R24, R25: 5.1K/5%; R_0603_1608Metric
R26: 100R/5%; R_0603_1608Metric
U3: USBLC6-2SC6; SOT-23-6

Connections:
+3.3V: J1.5, J3.5, R7.1, R26.2; also elsewhere on the board
DBG_RST: J1.4, R12.1
DBG_SWCLK: J1.2, R8.2, R14.1
DBG_SWDIO: J1.3, R7.2, R13.1
GND: J1.1, J2.1, J3.1, J4.A1 (GND), J4.A12 (GND), J4.B1 (GND), J4.B12 (GND), J4.S1 (SHIELD), R8.1, R24.2, R25.2, R28.1, U3.2 (GND); also elsewhere on the board
MCU_RX: J2.2; also elsewhere on the board
MCU_TX: J2.3; also elsewhere on the board
MISO: J3.3; also elsewhere on the board
MOSI: J3.2; also elsewhere on the board
unnamed: H7.1, J4.A8 (SBU1)
unnamed: H8.1, J4.B8 (SBU2)
unnamed: J4.A5 (CC1), R24.1
unnamed: J4.A6 (D+), J4.B6 (D+), U3.3 (I/O2)
unnamed: J4.A7 (D-), J4.B7 (D-), U3.1 (I/O1)
unnamed: J4.B5 (CC2), R25.1
unnamed: Q1.2 (S), R26.1
unnamed: Q1.3 (D), R11.2
unnamed: R9.1, U3.6 (I/O1)
unnamed: R10.1, R11.1, U3.4 (I/O2)
RESET: R12.2; also elsewhere on the board
SCK: J3.4; also elsewhere on the board
SWCLK: R13.2; also elsewhere on the board
SWDIO: R14.2; also elsewhere on the board
USB_D+: R10.2; also elsewhere on the board
USB_D-: R9.2; also elsewhere on the board
USB_EN: Q1.1 (G), R28.2; also elsewhere on the board
VIN: J4.A4 (VBUS), J4.A9 (VBUS), J4.B4 (VBUS), J4.B9 (VBUS), U3.5 (VBUS); also elsewhere on the board

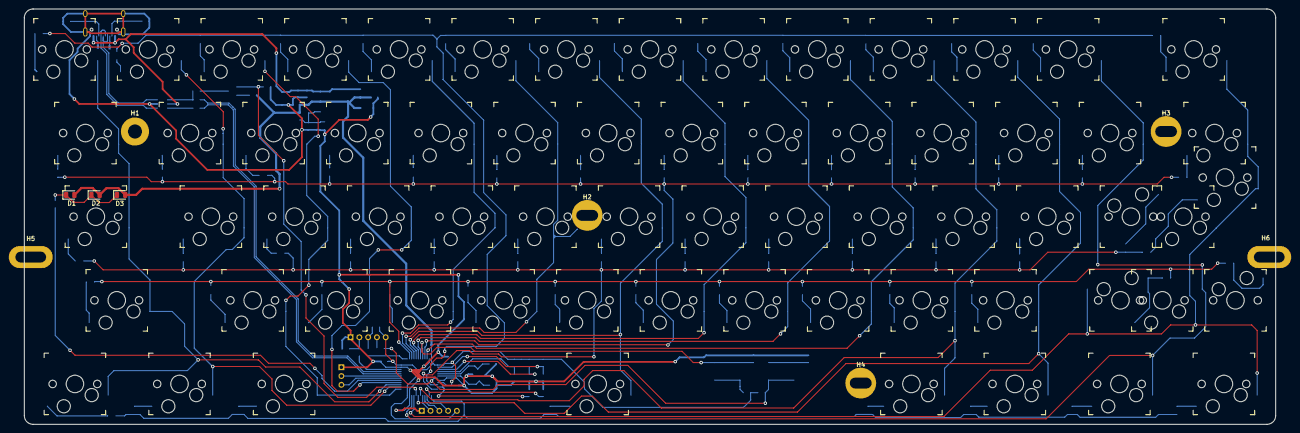
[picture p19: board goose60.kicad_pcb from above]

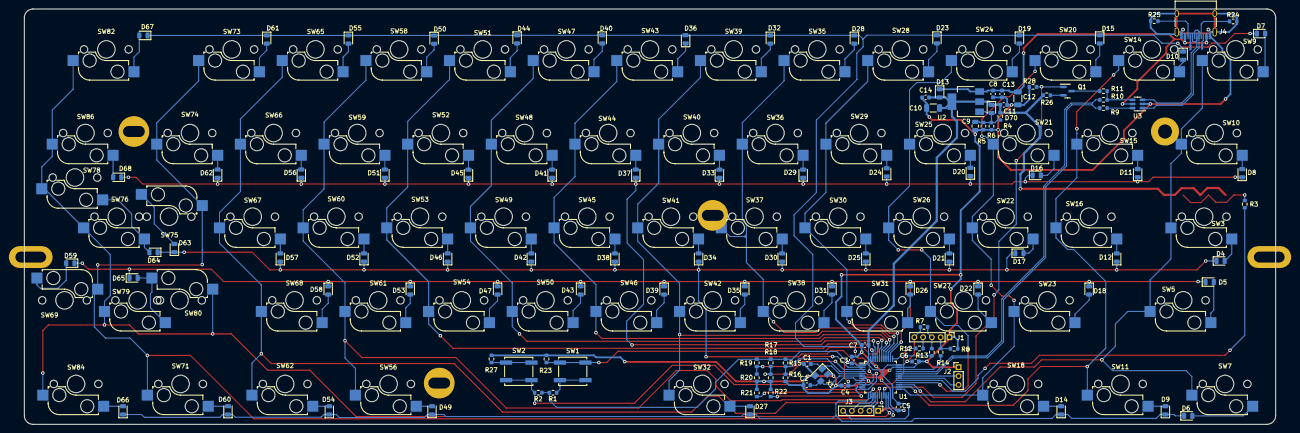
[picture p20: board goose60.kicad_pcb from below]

Board: 2 copper layers, 285.0 x 94.6 mm, 194 parts (120 on the bottom side), 122 nets.

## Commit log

2022-07-15 init project
    [goose60.kicad_pcb, goose60.kicad_sch, leds.kicad_sch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]
2022-07-18 add gh60 lib to project
    [goose60.kicad_pcb, goose60.kicad_sch, leds.kicad_sch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]
2022-07-30 add kailh socket lib submodule
2022-07-31 clean goose60 project re-defined sch
    [goose60.kicad_pcb, goose60.kicad_sch, leds.kicad_sch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]
2022-07-31 init new project
    [goose60.kicad_pcb, goose60.kicad_sch]
2022-07-31 add new design
    [Interface.kicad_sch, PowerManager.kicad_sch, goose60.kicad_pcb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]
2022-08-01 update goose60 sch footprint
    [Interface.kicad_sch, PowerManager.kicad_sch, goose60.kicad_pcb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]
2022-08-02 update footpoint and add pcb layout
    [Interface.kicad_sch, goose60.kicad_pcb, goose60.kicad_sch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]
2022-08-02 update diode location
    [goose60.kicad_pcb]
2022-08-03 remove key
    [goose60.kicad_pcb, goose60.kicad_sch, switches.kicad_sch]
2022-08-03 update components location
    [Interface.kicad_sch, PowerManager.kicad_sch, goose60.kicad_pcb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]
2022-08-04 add HOLE
    [goose60.kicad_pcb]
2022-08-05 update MX socket loaction
    [goose60.kicad_pcb, goose60.kicad_sch]
2022-08-06 add res and fix rule check fail problom
    [Interface.kicad_sch, PowerManager.kicad_sch, goose60.kicad_pcb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]
2022-08-07 change pin default and try layout
    [Interface.kicad_sch, goose60.kicad_pcb, goose60.kicad_sch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]
2022-08-08 update pcb layout and pin defined
    [goose60.kicad_pcb, goose60.kicad_sch]
2022-08-09 add usb enable pin
    [Interface.kicad_sch, goose60.kicad_pcb, goose60.kicad_sch]
2022-08-09 add gh60 mechanism hole
    [goose60.kicad_pcb, goose60.kicad_sch]
2022-08-10 update MCU VCC and GND layout
    [Interface.kicad_sch, goose60.kicad_pcb]
2022-08-10 fix pcb edge cuts link error
    [goose60.kicad_pcb]
2022-08-13 fix usb type-c location
    [goose60.kicad_pcb]
2022-08-15 modify power/bootload circuit
    [Interface.kicad_sch, PowerManager.kicad_sch, goose60.kicad_sch]
2022-08-17 modify pcb footprint
    [Interface.kicad_sch, PowerManager.kicad_sch, goose60.kicad_sch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]
2022-08-18 change Diode direction and update PR #1 footprint
    [Interface.kicad_sch, PowerManager.kicad_sch, goose60.kicad_pcb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]
2022-08-19 fix layout rule error and warring
    [goose60.kicad_pcb]
2022-08-20 fix diode direction on row1
    [switches.kicad_sch]
2022-08-24 update pcb layout
    [Interface.kicad_sch, goose60.kicad_sch]
2022-08-25 update pcb layout and add GND via
    [Interface.kicad_sch, goose60.kicad_sch]
2022-08-26 update XTAL ground via and layout
2022-08-27 clean pcb layer and add readme file
    * BOM
    * layout
    * pcb PDF file
    * sch PDF file
    [goose60_bom.csv]
2022-08-28 add iso layout "iso /" key
    [goose60.kicad_sch, goose60_bom.csv, switches.kicad_sch]
2022-08-28 remove ISO layout
    * iso layout fork to cattle60 project
    [goose60.kicad_sch, goose60_bom.csv, switches.kicad_sch]
2022-08-30 change switch lib
2022-08-30 update keyswitch foodpoint
    [goose60.kicad_sch, goose60_bom.csv, switches.kicad_sch]
2022-08-30 remove switches.pretty library
2022-08-31 change MCU location and change row5 pin
    * row5 -> PB2
    [goose60.kicad_sch, goose60_bom.csv]
2022-09-01 change LDO ic and PCB layout
    [PowerManager.kicad_sch, goose60.kicad_sch, goose60_bom.csv]
2022-09-02 modify usb layout and add text to pcb
    [goose60_bom.csv]
2022-09-07 Add BOM list
    [goose60.xlsx]
2022-09-08 modify power manager value
    [PowerManager.kicad_sch, goose60.kicad_sch, goose60_bom.csv]
2022-09-28 update BOM
    [goose60.xlsx]
2022-10-15 update keyboard 3D object to PCB
